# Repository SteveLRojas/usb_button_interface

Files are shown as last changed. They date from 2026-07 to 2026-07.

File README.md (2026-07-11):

# usb_button_interface
Interface module that maps 6 button inputs to keyboard keys.  

## What is in this repo?
Here you will find the design files for a small custom PCB that lets you connect buttons or switches to a PC via USB and map them to keyboard buttons.  
The hardware is designed in KiCad, the design files are in the HW folder.  
The firmware is written in C and meant to be compiled with Keil uVison C51 and linked with LX51. The project makes extensive use of pointers and requires a linker script for correct memory overlay.  
The entire uVision project is in the FW folder.  
The SW folder contains test scripts as well as a command line tool (ubi_programmer.py) used to set the key mapping. To set the key mapping you need ubi_programmer.py, ubi_platform.py, and ubi_regs.py. The other files are test scripts.  

## How do I use this thing?
First you will need the hardware, boards can be ordered from JLCPCB and all the components are available from LCSC.  
Once you have working hardware close the jumper J6 to put it in programming mode, compile the firmware, and use WCHISP or a similar program to upload the firmware.  
After the firmware is uploaded remove jumper J6 to put the device in functional mode. Now when it is plugged into USB the LED will blink and then stay on, this means the device is in functional mode.  
Touching the capacitive touch button will make the LED turn off, this means the device is in configuration mode. Touching the button again will put the device back into functional mode.  
Note that the capacitive button is automatically calibrated each time the device is powered on, so while powering on the device make sure it is placed in its normal operating position and don't touch the capacitive button.  
When the device is in functional mode it should appear to the PC as a completely satandard USB keyboard, when it is in configuration mode it will appear as a CDC ACM device.  
There is no need to specify a serial port when running the configuration script, as it can scan the serial ports and automatically find the device.  

## How do I set the key mapping?
Use the provided python script (ubi_programmer.py). Run it with -h to see what arguments it supports.  
Example usage: python ubi_programmer.py --eeprom --sw0 0x1A --sw1 0x29  
The above example maps sw0 to the 'W' key, and sw1 to the escape key. The hexadecimal numbers representing each keyboard key can be found in the document "HID Usage Tables for Universal Serial Bus (USB)".  
The first time you configure the device you should specify all the switches (even if you don't intend to use them) to make sure nothing is mapped to an invalid key.

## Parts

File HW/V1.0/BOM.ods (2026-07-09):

Part | #Needed | #Owned | Satisfied? | Location
CH552G | 1 | 6 | TRUE | Project Box
MT9700 | 1 | 50 | TRUE | Project Box
LED Orange 0805 | 1 | 500 | TRUE | Project Box
74LVC1G17 | 8 | 50 | TRUE | Project Box
PTS810 (button) | 1 | 40 | TRUE | Switch Box
Capacitor 0.1u 0805 | 11 | 200 | TRUE | Project Box
Capacitor 0.01u 0805 | 8 | 900 | TRUE | Project Box
Capacitor 1u 0805 | 1 | 200 | TRUE | Box 7
Resistor 1K 0805 | 9 | 300 | TRUE | Box 8
Resistor 4K7 0805 | 1 | 50 | TRUE | Box 8
Resistor 5K1 0805 | 2 | 800 | TRUE | Box 10
Resistor 10K 0805 | 10 | 100 | TRUE | Box 10
Pin header 1.27mm 1x2 | 1 | 150 | TRUE | Connector Box
Power connector 4P 3.81mm | 4 | 10 | TRUE | Connector Box
Connector USB-C | 1 | 5 | TRUE | Connector Box

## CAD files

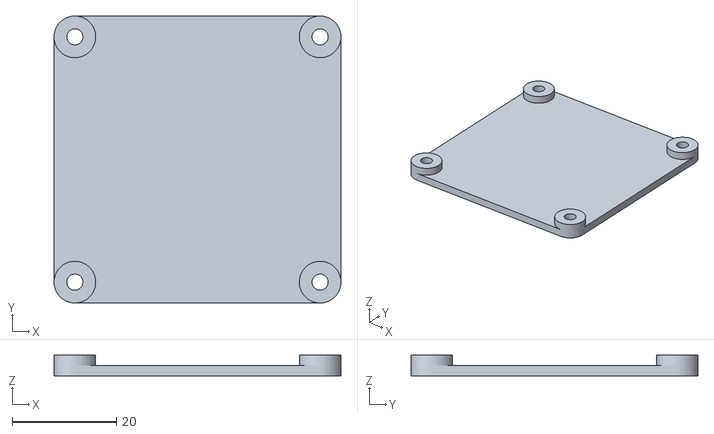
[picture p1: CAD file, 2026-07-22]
3d_models/usb_button_interface_base.stl
55.0 x 55.0 x 4.00

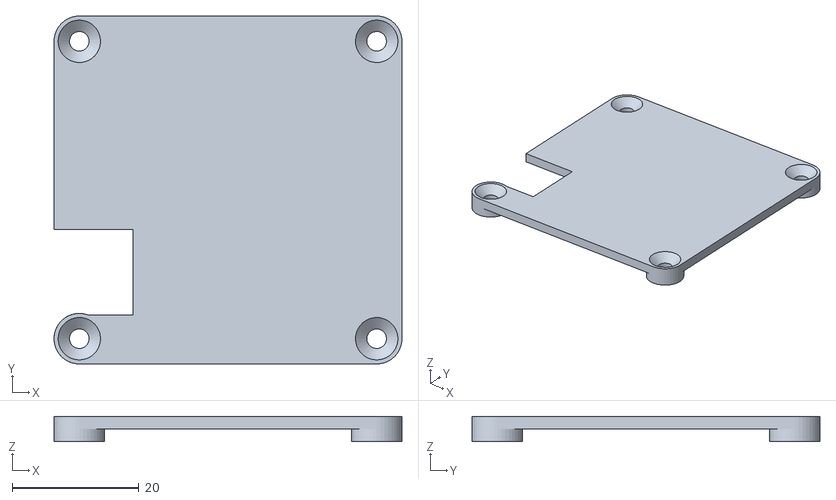
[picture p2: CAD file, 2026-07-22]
3d_models/usb_button_interface_top.stl
55.0 x 55.0 x 4.00

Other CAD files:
FW/usb_button_interface/Objects/usb_hid_keyboard.obj
3d_models/usb_button_interface_base.f3d
3d_models/usb_button_interface_top.f3d

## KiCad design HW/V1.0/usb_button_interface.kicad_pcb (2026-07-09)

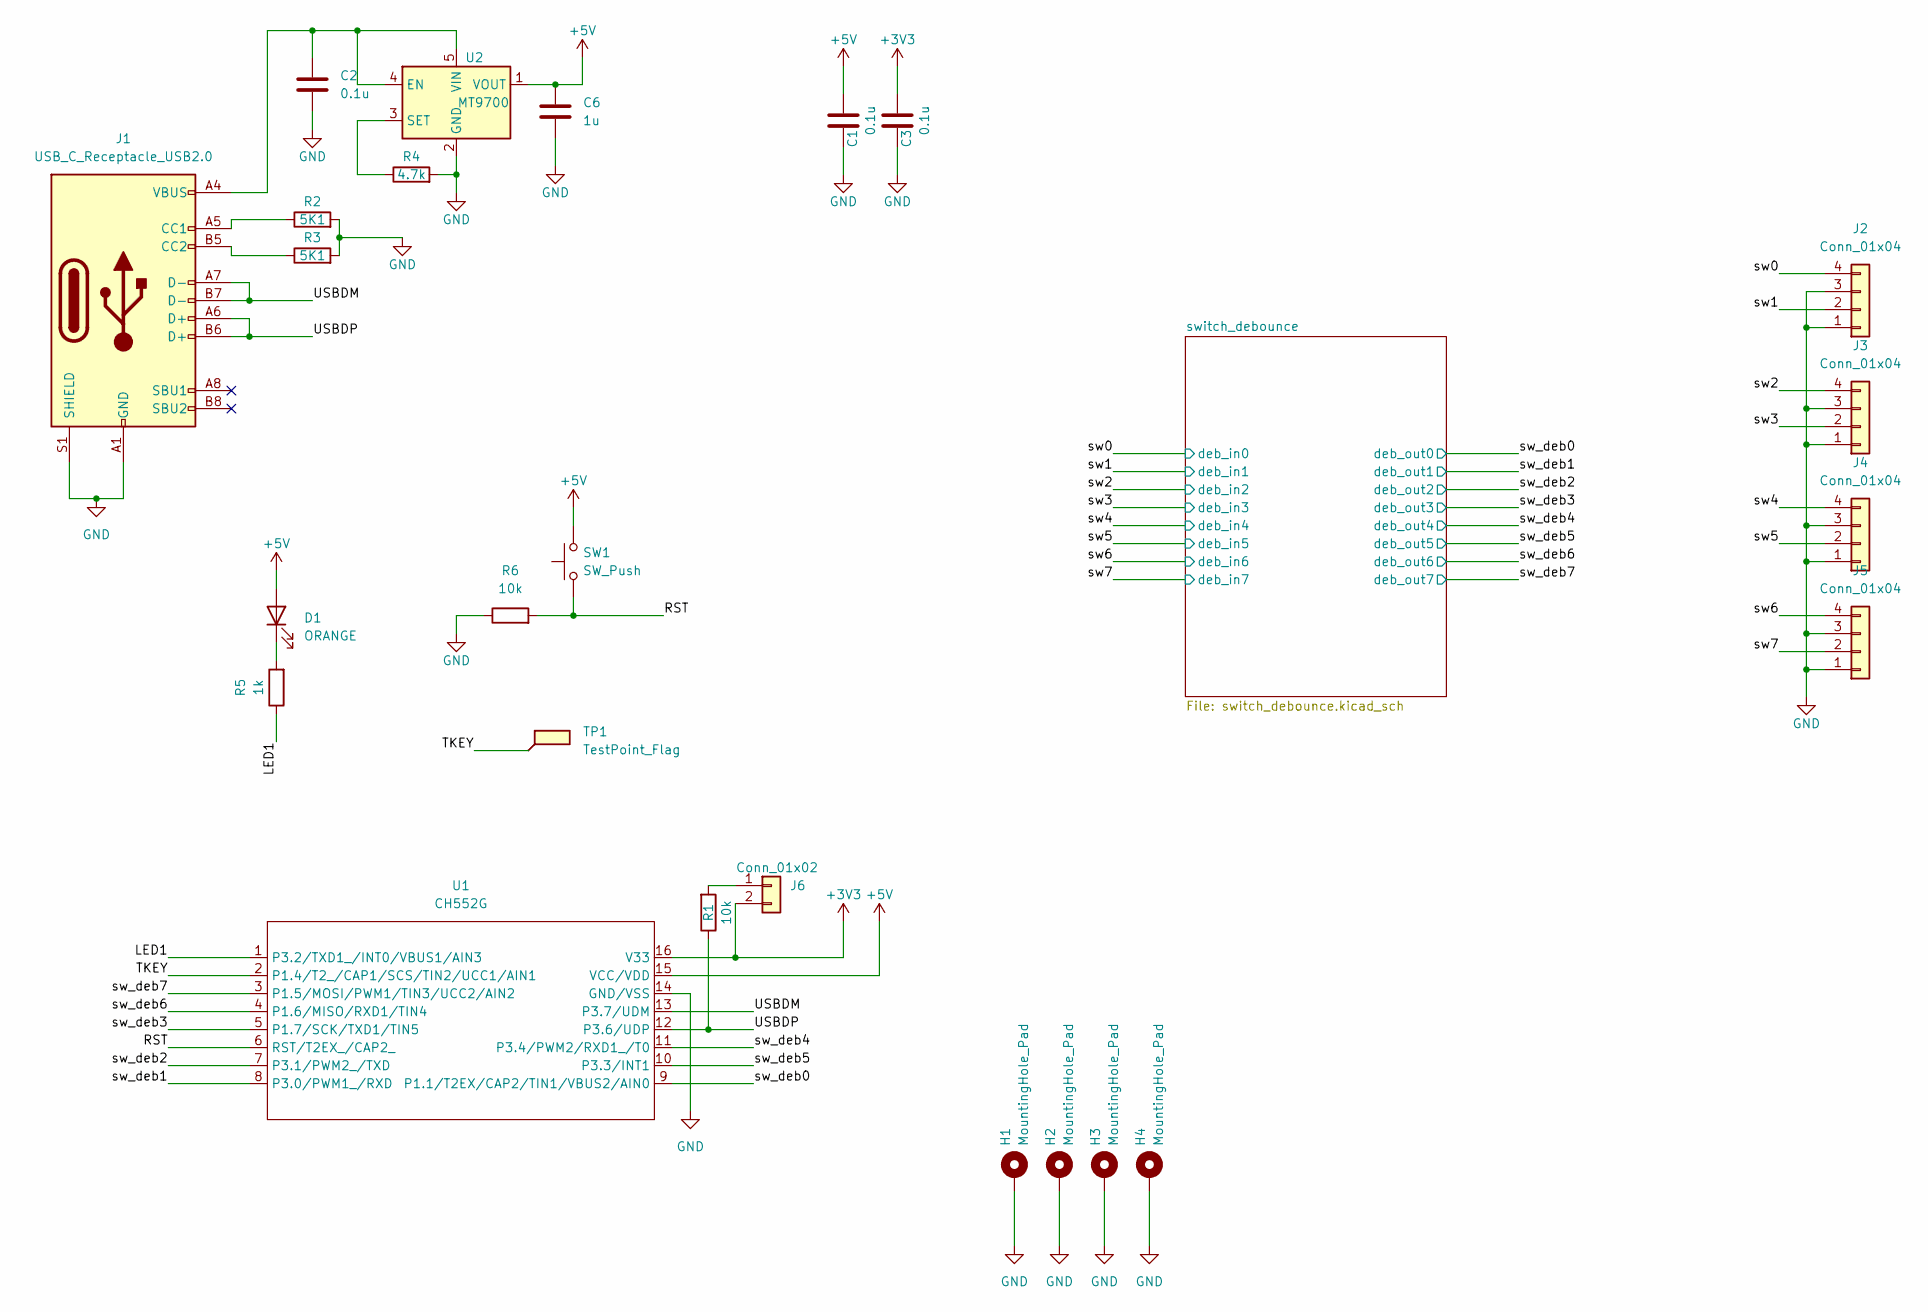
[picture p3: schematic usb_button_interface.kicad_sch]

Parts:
C1, C2, C3: 0.1u; C_0805_2012Metric
C6: 1u; C_0805_2012Metric
D1: ORANGE; LED_0805_2012Metric
H1, H2, H3, H4: MountingHole_Pad; MountingHole_3.2mm_M3_Pad
J1: USB_C_Receptacle_USB2.0; USB_C_Receptacle_HRO_TYPE-C-31-M-12
J2, J3, J4, J5: Conn_01x04; PhoenixContact_MC_1,5_4-G-3.81_1x04_P3.81mm_Horizontal
J6: Conn_01x02; PinHeader_1x02_P1.27mm_Vertical
R1, R6: 10k; R_0805_2012Metric
R2, R3: 5K1; R_0805_2012Metric
R4: 4.7k; R_0805_2012Metric
R5: 1k; R_0805_2012Metric
SW1: SW_Push; SW_SPST_PTS810
TP1: TestPoint_Flag; CapTouch_10mm
U1: CH552G; SO-16_3.9x9.9mm_P1.27mm
U2: MT9700; SOT-23-5

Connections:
+3V3: C3.1, J6.2, U1.16 (V33)
+5V: C1.1, C6.1, D1.2 (A), SW1.2, U1.15 (VCC/VDD), U2.1 (VOUT); also elsewhere on the board
/LED1: R5.1, U1.1 (P3.2/TXD1_/INT0/VBUS1/AIN3)
/RST: R6.2, SW1.1, U1.6 (RST/T2EX_/CAP2_)
/TKEY: TP1.1, U1.2 (P1.4/T2_/CAP1/SCS/TIN2/UCC1/AIN1)
/USBDM: J1.A7 (D-), J1.B7 (D-), U1.13 (P3.7/UDM)
/USBDP: J1.A6 (D+), J1.B6 (D+), R1.1, U1.12 (P3.6/UDP)
/sw0: J2.4; also elsewhere on the board
/sw1: J2.2; also elsewhere on the board
/sw2: J3.4; also elsewhere on the board
/sw3: J3.2; also elsewhere on the board
/sw4: J4.4; also elsewhere on the board
/sw5: J4.2; also elsewhere on the board
/sw6: J5.4; also elsewhere on the board
/sw7: J5.2; also elsewhere on the board
/sw_deb0: U1.9 (P1.1/T2EX/CAP2/TIN1/VBUS2/AIN0); also elsewhere on the board
/sw_deb1: U1.8 (P3.0/PWM1_/RXD); also elsewhere on the board
/sw_deb2: U1.7 (P3.1/PWM2_/TXD); also elsewhere on the board
/sw_deb3: U1.5 (P1.7/SCK/TXD1/TIN5); also elsewhere on the board
/sw_deb4: U1.11 (P3.4/PWM2/RXD1_/T0); also elsewhere on the board
/sw_deb5: U1.10 (P3.3/INT1); also elsewhere on the board
/sw_deb6: U1.4 (P1.6/MISO/RXD1/TIN4); also elsewhere on the board
/sw_deb7: U1.3 (P1.5/MOSI/PWM1/TIN3/UCC2/AIN2); also elsewhere on the board
GND: C1.2, C2.2, C3.2, C6.2, H1.1, H2.1, H3.1, H4.1, J1.A1 (GND), J1.A12 (GND), J1.B1 (GND), J1.B12 (GND), J1.S1 (SHIELD), J2.1, J2.3, J3.1, J3.3, J4.1, J4.3, J5.1, J5.3, R2.2, R3.2, R4.2, R6.1, U1.14 (GND/VSS), U2.2 (GND); also elsewhere on the board
unnamed: C2.1, J1.A4 (VBUS), J1.A9 (VBUS), J1.B4 (VBUS), J1.B9 (VBUS), U2.4 (EN), U2.5 (VIN)
unnamed: D1.1 (K), R5.2
unnamed: J1.A5 (CC1), R2.1
unnamed: J1.B5 (CC2), R3.1
unnamed: J6.1, R1.2
unnamed: R4.1, U2.3 (SET)

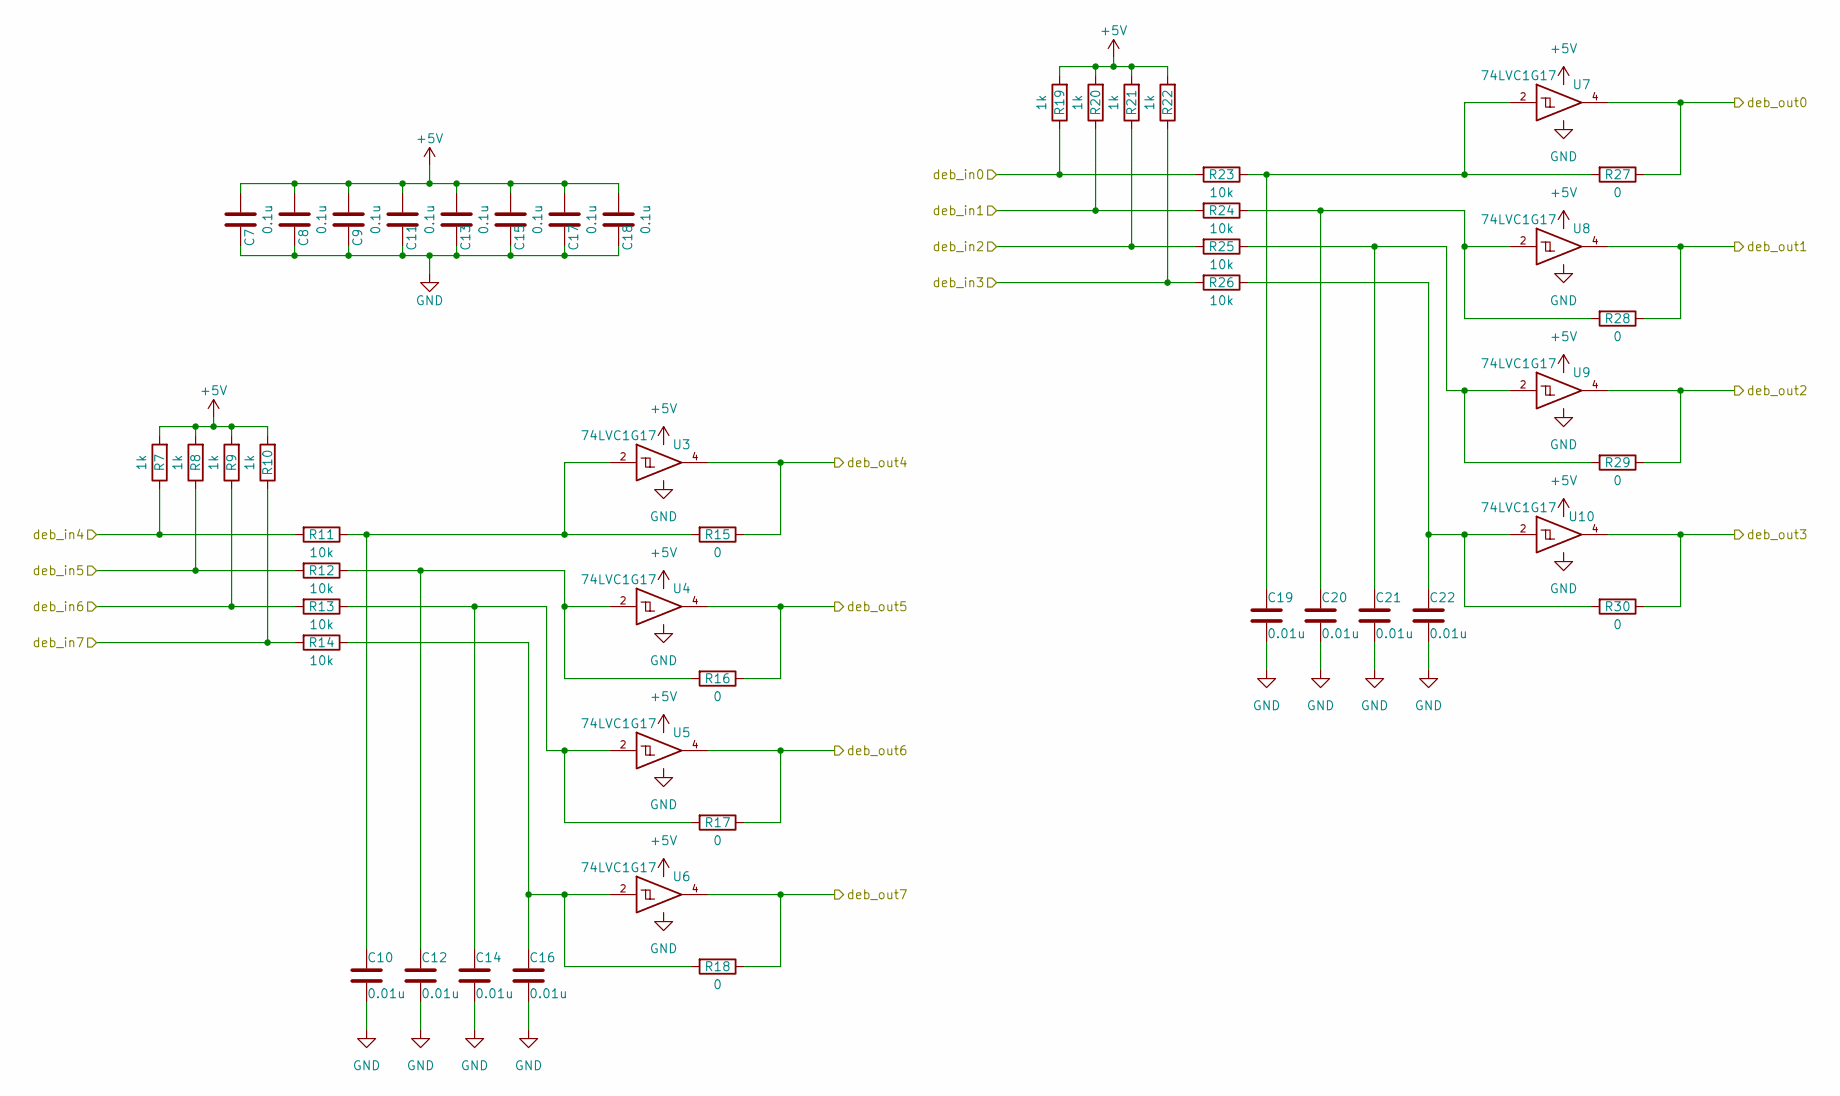
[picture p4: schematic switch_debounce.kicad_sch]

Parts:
C7, C8, C9, C11, C13, C15, C17, C18: 0.1u; C_0805_2012Metric
C10, C12, C14, C16, C19, C20, C21, C22: 0.01u; C_0805_2012Metric
R7, R8, R9, R10, R19, R20, R21, R22: 1k; R_0805_2012Metric
R11, R12, R13, R14, R23, R24, R25, R26: 10k; R_0805_2012Metric
R15, R16, R17, R18, R27, R28, R29, R30: 0; R_0805_2012Metric
U3, U4, U5, U6, U7, U8, U9, U10: 74LVC1G17; SOT-353_SC-70-5

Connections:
+5V: C7.1, C8.1, C9.1, C11.1, C13.1, C15.1, C17.1, C18.1, R7.2, R8.2, R9.2, R10.2, R19.2, R20.2, R21.2, R22.2, U3.5 (VCC), U4.5 (VCC), U5.5 (VCC), U6.5 (VCC), U7.5 (VCC), U8.5 (VCC), U9.5 (VCC), U10.5 (VCC); also elsewhere on the board
/sw0: R19.1, R23.2; also elsewhere on the board
/sw1: R20.1, R24.2; also elsewhere on the board
/sw2: R21.1, R25.2; also elsewhere on the board
/sw3: R22.1, R26.2; also elsewhere on the board
/sw4: R7.1, R11.2; also elsewhere on the board
/sw5: R8.1, R12.2; also elsewhere on the board
/sw6: R9.1, R13.2; also elsewhere on the board
/sw7: R10.1, R14.2; also elsewhere on the board
/sw_deb0: R27.1, U7.4; also elsewhere on the board
/sw_deb1: R28.1, U8.4; also elsewhere on the board
/sw_deb2: R29.1, U9.4; also elsewhere on the board
/sw_deb3: R30.1, U10.4; also elsewhere on the board
/sw_deb4: R15.1, U3.4; also elsewhere on the board
/sw_deb5: R16.1, U4.4; also elsewhere on the board
/sw_deb6: R17.1, U5.4; also elsewhere on the board
/sw_deb7: R18.1, U6.4; also elsewhere on the board
GND: C7.2, C8.2, C9.2, C10.1, C11.2, C12.1, C13.2, C14.1, C15.2, C16.1, C17.2, C18.2, C19.1, C20.1, C21.1, C22.1, U3.3 (GND), U4.3 (GND), U5.3 (GND), U6.3 (GND), U7.3 (GND), U8.3 (GND), U9.3 (GND), U10.3 (GND); also elsewhere on the board
unnamed: C10.2, R11.1, R15.2, U3.2
unnamed: C12.2, R12.1, R16.2, U4.2
unnamed: C14.2, R13.1, R17.2, U5.2
unnamed: C16.2, R14.1, R18.2, U6.2
unnamed: C19.2, R23.1, R27.2, U7.2
unnamed: C20.2, R24.1, R28.2, U8.2
unnamed: C21.2, R25.1, R29.2, U9.2
unnamed: C22.2, R26.1, R30.2, U10.2

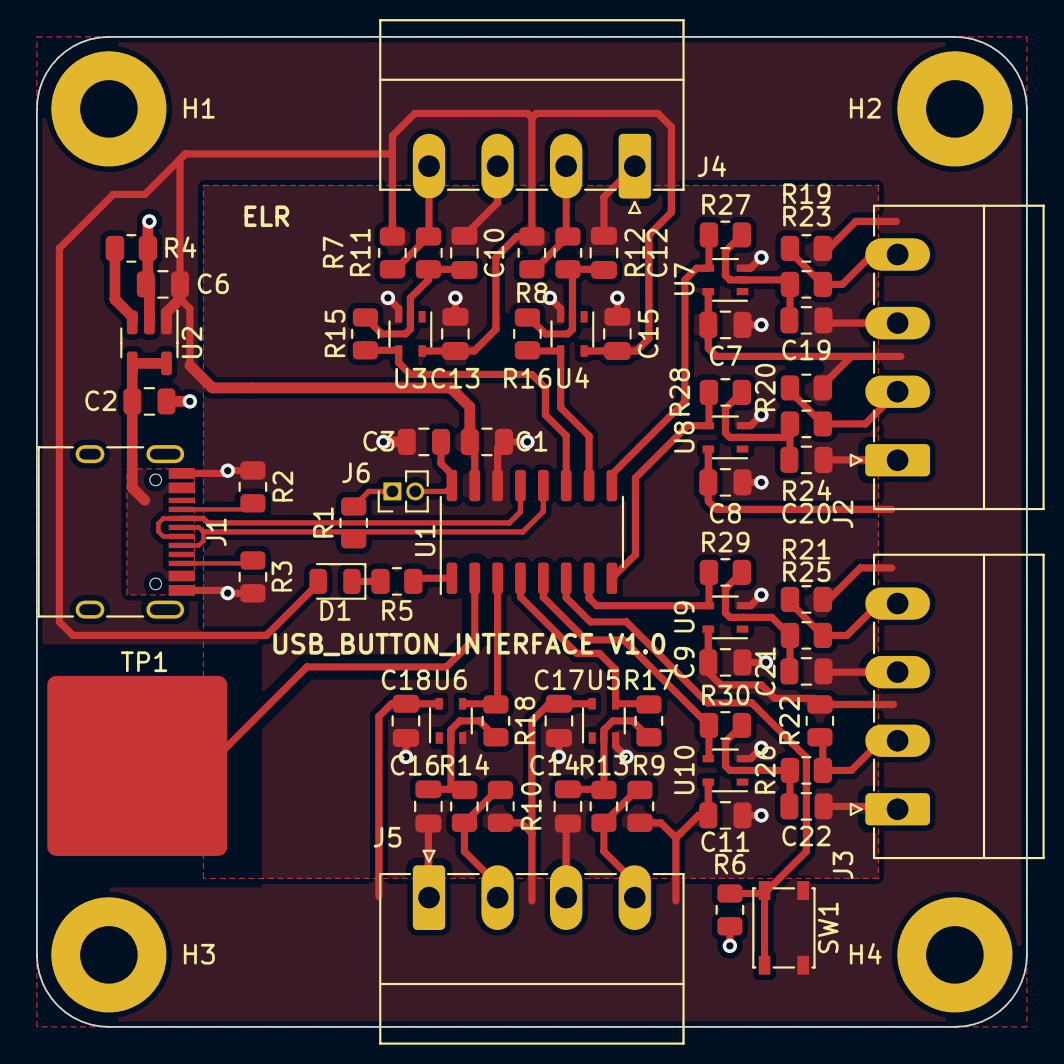
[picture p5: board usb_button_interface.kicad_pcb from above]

Board: 2 copper layers, 55.0 x 55.0 mm, 73 parts (0 on the bottom side), 38 nets.

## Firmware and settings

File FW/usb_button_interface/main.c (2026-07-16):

#include "CH552.H"
#include "CH552_FLASH.h"
#include "CH552_GPIO.h"
#include "CH552_RCC.h"
#include "CH552_TKEY.h"
#include "CH552_USB.h"
#include "CH552_USB_CDC.h"
#include "CH552_USB_HID_KB.h"
#include "CH552_TIMER.h"

#define DEBOUNCE_SAMPLES 200

//Pins:
// SW0 = P11
// TKEY = P14
// SW7 = P15
// SW6 = P16
// SW3 = P17
// SW1 = P30
// SW2 = P31
// LED1 = P32
// SW5 = P33
// SW4 = P34
// UDP = P36
// UDM = P37

typedef struct _KEY_MAP {
	UINT8 len;
	UINT8 sw_pol;
	UINT8 sw_keys[6];
} key_map_t;

key_map_t key_map;

//HINT: returns an address out of range if all blocks are valid
UINT8 find_blank_key_map(void)
{
	UINT8 block_offset = 0;
	
	while((block_offset < 0x80) && (flash_read_byte(block_offset) == 8))
	{
		block_offset += 8;
	}
	return block_offset;
}

void load_key_map(void)
{
	UINT8 block_offset;
	
	block_offset = find_blank_key_map();
	block_offset -= 8;	//HINT: goes out of range if there are no valid blocks
	
	flash_read(block_offset, (UINT8*)&key_map, 8);
}

void write_key_map(void)
{
	UINT8 block_offset;
	
	block_offset = find_blank_key_map();
	if(block_offset > 0x7F)
	{
		flash_clear_range(0, 0, 0xFF);
		block_offset = 0x00;
	}
	
	flash_write(block_offset, (UINT8*)&key_map, 8);
}

int main(void)
{
	UINT8 tkey_time = 0;
	UINT8 dev_mode = 0;
	UINT8 prev_tkey_state;
	
	UINT8 prev_control_line_state;
	UINT8 datagram[2];
	UINT16 bytes_available;
	UINT8 temp;
	
	UINT8 map_idx;
	UINT8 flash_idx;
	
	UINT8 hid_kb_idle_time = 0;
	UINT8 sw_state;
	UINT8 sw_count[6];
	UINT8 sw_debounced = 0;
	UINT8 prev_sw_debounced = 0;
	
	rcc_set_clk_freq(RCC_CLK_FREQ_24M);
	
	gpio_set_mode(GPIO_MODE_INPUT, GPIO_PORT_1, GPIO_PIN_7 | GPIO_PIN_6 | GPIO_PIN_5 | GPIO_PIN_4 | GPIO_PIN_1);
	gpio_set_mode(GPIO_MODE_INPUT, GPIO_PORT_3, GPIO_PIN_4 | GPIO_PIN_3 | GPIO_PIN_1 | GPIO_PIN_0);
	gpio_set_mode(GPIO_MODE_PP, GPIO_PORT_3, GPIO_PIN_2);
	
	timer_init(TIMER_0, NULL);
	timer_set_period(TIMER_0, 4ul * FREQ_SYS / 1000ul);	//period is 4ms
	timer_init(TIMER_1, NULL);
	timer_set_period(TIMER_1, FREQ_SYS / 1000ul);	//period is 1ms
	EA = 1;	//enable interupts
	E_DIS = 0;
	
	RESET_KEEP = rcc_get_rst_typ();
	if((RESET_KEEP == RCC_RST_TYP_WDOG) || (RESET_KEEP == RCC_RST_TYP_SOFT))
	{
		rcc_delay_ms(500);
	}
	else
	{
		timer_long_delay(TIMER_1, 250);
	}
	
	tkey_init(TKEY_FAST);
	tkey_schedule[0] = TKEY_TIN2_P14;
	tkey_schedule_len = 1;
	tkey_init_schedule();
	tkey_calibrate();
	tkey_threshold = 0x200;
	tkey_run_schedule(1);
	while(tkey_pending_samples);
	prev_tkey_state = tkey_results[0];
	
	gpio_clear_pin(GPIO_PORT_3, GPIO_PIN_2);
	timer_long_delay(TIMER_1, 250);
	gpio_set_pin(GPIO_PORT_3, GPIO_PIN_2);
	timer_long_delay(TIMER_1, 250);
	gpio_clear_pin(GPIO_PORT_3, GPIO_PIN_2);

	timer_start(TIMER_0);
	load_key_map();
	hid_kb_init();
	
	if(key_map.len != 8)
	{
		sw_debounced = 0xFF;
		prev_sw_debounced = 0xFF;
	}
	
	for(map_idx = 0; map_idx < 6; ++map_idx)
	{
		sw_count[map_idx] = 0;
	}
	
	while(TRUE)
	{
		//Update timers
		if(timer_overflow_counts[TIMER_0])	//HINT: timer interval is 4ms
		{
			++tkey_time;
			++hid_kb_idle_time;
			timer_overflow_counts[TIMER_0] = 0;
		}
		
		//Update touck key state
		if(tkey_time >= 32)
		{
			tkey_run_schedule(1);
			tkey_time = 0;
		}
		
		//Handle mode switching
		if(tkey_results[0] && !prev_tkey_state)
		{
			dev_mode = !dev_mode;
			gpio_write_pin(GPIO_PORT_3, GPIO_PIN_2, dev_mode);
			usb_disconnect();
			timer_long_delay(TIMER_1, 250);
			cdc_config = 0;
			hid_kb_config = 0;
			if(dev_mode)
			{
				cdc_init();
				cdc_set_serial_state(CDC_SS_TXCARRIER | CDC_SS_RXCARRIER);
				prev_control_line_state = cdc_control_line_state;
			}
			else
			{
				hid_kb_init();
			}
		}
		prev_tkey_state = tkey_results[0];
		
		if(dev_mode && cdc_config)	//programming mode
		{
			bytes_available = cdc_bytes_available();
			temp = cdc_peek();
			if((bytes_available >= 2) && (temp & 0x80))	//Handle write datagram
			{
				cdc_read_bytes(datagram, 2);
			
				switch(datagram[0] & 0x7F)
				{
					case 0x08:
						map_idx = datagram[1];
						break;
					case 0x09:
						((UINT8*)&key_map)[map_idx & 0x07] = datagram[1];
						++map_idx;
						break;
					case 0x0A:
						load_key_map();
						break;
					case 0x0B:
						write_key_map();
						break;
					case 0x0D:
						flash_idx = datagram[1];
						break;
					case 0x0E:
						flash_write_byte(flash_idx & 0x7F, datagram[1]);
						++flash_idx;
						break;
					case 0x0F:
						flash_clear_range(0, 0, 0xFF);
						break;
				}
			}
			else if(bytes_available && !(temp & 0x80))	//handle read datagram
			{
				datagram[0] = cdc_read_byte();
			
				switch(datagram[0])
				{
					case 0x00:	//device_id[0]
						datagram[0] = 'U';
						break;
					case 0x01:	//device_id[1]
						datagram[0] = 'B';
						break;
					case 0x02:	//device_id[2]
						datagram[0] = 'I';
						break;
					case 0x03:	//device_id[3]
						datagram[0] = '1';
						break;
					
					case 0x04:	//unique_id[0]
						datagram[0] = (UINT8)(*(UINT16 code*)ROM_CHIP_ID_LO);
						break;
					case 0x05:	//unique_id[1]
						datagram[0] = (UINT8)((*(UINT16 code*)ROM_CHIP_ID_LO) >> 8);
						break;
					case 0x06:	//unique_id[2]
						datagram[0] = (UINT8)(*(UINT16 code*)ROM_CHIP_ID_HI);
						break;
					case 0x07:	//unique_id[3]
						datagram[0] = (UINT8)((*(UINT16 code*)ROM_CHIP_ID_HI) >> 8);
						break;
					
					case 0x08:
						datagram[0] = map_idx;
						break;
					case 0x09:
						datagram[0] = ((UINT8*)&key_map)[map_idx];
						++map_idx;
						break;
					case 0x0C:
						datagram[0] = find_blank_key_map();
						break;
					case 0x0D:
						datagram[0] = flash_idx;
						break;
					case 0x0E:
						datagram[0] = flash_read_byte(flash_idx);
						++flash_idx;
						break;
				}
				
				cdc_write_byte(datagram[0]);
			}
			else if(bytes_available)	//datagrams not received in a single transfer are ignored
			{
				cdc_read_bytes(datagram, bytes_available);	//get rid of the extra bytes
			}
		
			if(prev_control_line_state != cdc_control_line_state)
			{
				cdc_set_serial_state(cdc_control_line_state & 3);
				prev_control_line_state = cdc_control_line_state;
			}
		}
		else if(!dev_mode && hid_kb_config)	//functional mode
		{
			temp = 0x01;
			sw_state = 0;
			if(gpio_read_pin(GPIO_PORT_1, GPIO_PIN_1))	//SW0
				sw_state |= temp;
			temp <<= 1;
			if(gpio_read_pin(GPIO_PORT_3, GPIO_PIN_0))	//SW1
				sw_state |= temp;
			temp <<= 1;
			if(gpio_read_pin(GPIO_PORT_3, GPIO_PIN_1))	//SW2
				sw_state |= temp;
			temp <<= 1;
			if(gpio_read_pin(GPIO_PORT_1, GPIO_PIN_7))	//SW3
				sw_state |= temp;
			temp <<= 1;
			if(gpio_read_pin(GPIO_PORT_3, GPIO_PIN_4))	//SW4
				sw_state |= temp;
			temp <<= 1;
			if(gpio_read_pin(GPIO_PORT_3, GPIO_PIN_3))	//SW5
				sw_state |= temp;
			
			sw_state ^= key_map.sw_pol;
			
			temp = 0x01;
			for(map_idx = 0; map_idx < 6; ++map_idx)
			{	
				if(sw_state & temp)
					sw_count[map_idx] += (sw_count[map_idx] <= DEBOUNCE_SAMPLES);
				else
					sw_count[map_idx] -= (sw_count[map_idx] != 0);
				
				if(!sw_count[map_idx])
					sw_debounced &= ~temp;
				if(sw_count[map_idx] == DEBOUNCE_SAMPLES)
					sw_debounced |= temp;
				
				temp <<= 1;
			}
			
			temp = sw_debounced & ~prev_sw_debounced;
			for(map_idx = 0; map_idx < 6; ++map_idx)
			{
				if(temp & 0x01)
					hid_kb_press_key(key_map.sw_keys[map_idx]);
				temp >>= 1;
			}
			
			temp = prev_sw_debounced & ~sw_debounced;
			for(map_idx = 0; map_idx < 6; ++map_idx)
			{
				if(temp & 0x01)
					hid_kb_release_key(key_map.sw_keys[map_idx]);
				temp >>= 1;
			}
			
			prev_sw_debounced = sw_debounced;
			
			if(hid_kb_idle_rate && (hid_kb_idle_time >= hid_kb_idle_rate))
			{
				hid_kb_send_report();
				hid_kb_idle_time = 0;
			}
		}
	}
}

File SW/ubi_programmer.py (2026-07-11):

import argparse
import time
import ubi_platform as ubi

def hex_byte(value):
    try:
        num = int(value, 0)    # accepts 0x27, 0X27, or even decimal
    except ValueError:
        raise argparse.ArgumentTypeError(f"'{value}' is not a valid number")

    if not 0 <= num <= 0xFF:
        raise argparse.ArgumentTypeError(f"{value} is outside the range 0x00-0xFF")

    return num


def main():
	parser = argparse.ArgumentParser(description="Configure HID key mappings")

	# SRAM / EEPROM
	group = parser.add_mutually_exclusive_group(required=True)
	group.add_argument("--sram", action="store_true", help="Store mapping in SRAM (temporary)")
	group.add_argument("--eeprom", action="store_true", help="Store mapping in EEPROM (persistent)")

	# Six switch mappings
	for i in range(6):
		parser.add_argument(f"--sw{i}", type=hex_byte, metavar="HEX", help=f"Key mapping for switch {i} (0x00-0xFF)")
		parser.add_argument(f"--sw{i}-pol", type=str.lower, choices=["no", "nc"], default="no", metavar="POLARITY", help=f"Switch {i} polarity (NO or NC, default: NO)")

	args = parser.parse_args()

	unique_id = ubi.init(0)
	if unique_id == 0:
		print("Could not find programming interface")
		exit(1)
	
	print(f"Device ID: {ubi.get_device_id():08X}")
	print(f"Unique ID: {ubi.get_unique_id():08X}")

	print(f"Blank key map address: {ubi.read_reg(ubi.regs.R_BLANK_MAP_ADDR):02X}")

	print("Current key map:")
	key_map = list(ubi.read_key_map())
	print(", ".join(f"{v:02X}" for v in key_map))

	key_map[0] = 0x08
	mask = 0x01
	for i in range(6):
		value = getattr(args, f"sw{i}")
		pol = getattr(args, f"sw{i}_pol")
		if value is not None:
			key_map[i + 2] = value
			key_map[1] &= ~mask
			if pol == "no":
				key_map[1] |= mask
		mask <<= 1

	ubi.write_key_map(key_map)
	if args.eeprom:
		ubi.write_reg(ubi.regs.R_WRITE_KEY_MAP, 0)
		time.sleep(0.25)

	print("New key map:")
	key_map = ubi.read_key_map()
	print(", ".join(f"{v:02X}" for v in key_map))

	if args.eeprom:
		print("EEPROM content:")
		eeprom = ubi.read_eeprom(0, 128)
		for i in range(0, len(eeprom), 8):
			print(", ".join(f"{v:02X}" for v in eeprom[i:i+8]))
	
	print("Done!")
	return 0

if __name__ == "__main__":
	main()

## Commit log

2026-07-09 Added hardware design files
    [BOM.ods, switch_debounce.kicad_sch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]
2026-07-09 Added preliminary firmware
    [usb_hid_keyboard.obj]
2026-07-09 Fixed bugs in firmware, added some test scripts
    [main.c, ubi_platform.py, ubi_status_check.py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]
2026-07-11 Added python script to configure the device and updated readme
2026-07-12 Added debouncing for the switch inputs
2026-07-16 Adjusted sensitivity of touch button to be way less sensitive
2026-07-22 Added 3D models
    [usb_button_interface_base.f3d, usb_button_interface_base.stl, usb_button_interface_top.f3d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]
